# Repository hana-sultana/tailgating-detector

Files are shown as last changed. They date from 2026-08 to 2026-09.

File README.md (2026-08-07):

# AI-Powered Tailgating Detection and Driver Alert System

A low-cost, fully offline ADAS prototype. A rear-facing Raspberry Pi Camera
Module 3 feeds a Raspberry Pi 5 running YOLO26n + ByteTrack; when a vehicle
stays below a distance threshold in the ego lane for a sustained period, the
Pi pushes a Bluetooth Low Energy notification to the driver's phone.

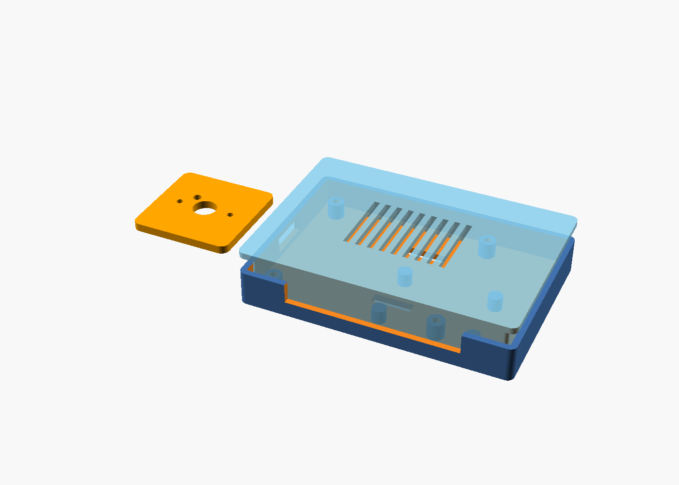
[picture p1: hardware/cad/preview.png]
Enclosure preview


## Architecture

```
Camera Module 3 ─CSI─> Raspberry Pi 5
                          │  Picamera2 capture (1280x720@30)
                          │  YOLO26n detection (imgsz=320, NMS-free)
                          │  ByteTrack persistent track IDs
                          │  Monocular distance (pinhole model + EMA smoothing)
                          │  Sliding-window decision (distance x time x lane)
                          └─BLE GATT notify──> Smartphone (nRF Connect / Flutter)
```

Everything runs on-device. No internet required or used.

## Repository layout

```
src/                   Python source (one module per pipeline stage)
  config.py            Every tunable, grouped by subsystem
  camera.py            Picamera2 backend + OpenCV fallback (video files!)
  detector.py          YOLO26n + ByteTrack wrapper
  distance_estimator.py  Pinhole-model distance + per-track smoothing
  tailgating_detector.py Decision logic (window, ratio, lane, cooldown)
  bluetooth.py         BLE GATT peripheral (bluezero/BlueZ)
  logger.py            Rotating logs + annotated event snapshots
  main.py              Entry point
tests/                 pytest unit tests for decision logic
hardware/
  cad/                 OpenSCAD source + printable STLs + preview
  diagrams/            Wiring and pinout
docs/                  BOM, calibration, testing, timeline, report skeleton
mobile/                Companion app design notes
```

## Install (on the Pi)

```bash
sudo apt update && sudo apt install -y python3-picamera2 bluez
git clone <your-repo-url> && cd tailgating-detector
python3 -m venv --system-site-packages .venv && source .venv/bin/activate
pip install ultralytics opencv-python numpy bluezero pytest
```

`--system-site-packages` lets the venv see the apt-installed picamera2.

## Run

```bash
cd src
python main.py                    # live camera
python main.py --video drive.mp4  # develop against recorded footage
python main.py --show             # with preview window (needs a display)
pytest ../tests -v                # decision-logic unit tests
```

First run downloads `yolo26n.pt` automatically. To receive alerts, open
nRF Connect on your phone, connect to **TailgateAlert**, and enable
notifications on the Alert characteristic.

## Key parameters (src/config.py)

| Parameter | Default | Meaning |
|---|---|---|
| `distance_threshold_m` | 8.0 | Closer than this = "too close" |
| `time_threshold_s` | 3.0 | Must persist this long |
| `violation_ratio` | 0.8 | Fraction of window frames below threshold |
| `lane_center_band` | 0.25 | Ego-lane filter (fraction of frame width) |
| `alert_cooldown_s` | 20.0 | Per-vehicle re-alert suppression |
| `imgsz` | 320 | Inference resolution (speed/accuracy trade) |

## Docs

- [Bill of Materials & cost](docs/BOM.md)
- [Wiring & assembly](hardware/diagrams/WIRING.md)
- [Camera calibration](docs/CALIBRATION.md)
- [Testing & validation plan](docs/TESTING.md)
- [Project timeline & risks](docs/TIMELINE.md)
- [Engineering report skeleton](docs/REPORT_OUTLINE.md)
- [Mobile app design](mobile/APP_DESIGN.md)

## Safety & legal notes

This is a driver-awareness prototype, not a certified safety device. It
must not be relied on for collision avoidance. Check local law before
mounting anything on a windshield/rear window, and mount the phone so
alerts don't create their own distraction (audio-only while driving).

## License

MIT (code). Note that Ultralytics YOLO weights are AGPL-3.0 — fine for a
personal/portfolio project; review licensing before any commercial use.

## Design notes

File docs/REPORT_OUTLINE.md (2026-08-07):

# Engineering Report — Outline & Research Direction

Skeleton for the final report (target 12–20 pages). Poster and slides
derive from the same structure.

1. **Abstract** — problem, approach, headline results (precision/recall,
   FPS, latency).
2. **Introduction & motivation** — rear-end collisions and tailgating as
   a factor; gap: production rear collision warning exists in new cars,
   not affordable retrofits.
3. **Related work** — see below.
4. **System design** — architecture diagram; hardware selection
   rationale (why Pi 5 / Camera Module 3 / BLE); enclosure design.
5. **Methodology** — YOLO26n choice & benchmarks; ByteTrack; pinhole
   distance model + calibration procedure; decision algorithm with the
   violation-ratio justification.
6. **Implementation** — module structure, offline-first constraints, BLE
   GATT design.
7. **Evaluation** — full metrics table from docs/TESTING.md; edge-case
   findings; thermal/power results.
8. **Limitations** — monocular depth assumptions, night performance,
   class-height bias, not a certified safety system.
9. **Future work** — ToF/radar fusion, Hailo acceleration, per-class
   heights, lane detection for curved-road filtering.
10. **Conclusion**, references, appendices (BOM, wiring, code listing).

## Research to cite (search terms → what it supports)

Find these on Google Scholar / arXiv and pick recent, well-cited
representatives — verify details before citing:

| Topic / search terms | Supports which section |
|---|---|
| "monocular distance estimation vehicle detection" | Methodology: pinhole model precedent & known error sources |
| "vision-based forward collision warning system" | Related work: the front-facing mirror of this project |
| "rear-end collision warning system" + NHTSA rear-end crash statistics | Motivation: problem scale |
| "ByteTrack multi-object tracking" (Zhang et al.) | Methodology: tracker choice |
| Ultralytics YOLO26 paper (arXiv 2606.03748) + "YOLO evolution overview" (arXiv 2510.09653) | Methodology: detector choice, NMS-free edge inference |
| "embedded deep learning inference Raspberry Pi benchmark" | Implementation: edge-AI feasibility |
| "time headway tailgating definition traffic safety" | Decision algorithm: the 2-second rule / headway literature justifies distance-x-time thresholds |
| "ADAS SAE J3016 levels" | Intro: where this sits (Level 0 warning system) |

Tip: the *time-headway* literature is the strongest academic anchor for
your decision rule — traffic engineering defines tailgating in seconds
of headway, not meters, which motivates a future version that scales
distance_threshold with ego speed (needs GPS/OBD speed input — good
future-work paragraph).

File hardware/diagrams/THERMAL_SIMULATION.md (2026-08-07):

# Thermal Simulation

## Why simulate thermal performance?

The Raspberry Pi 5's SoC dissipates around 6 W under sustained YOLO
inference. Enclosed in a plastic case inside a parked car that can hit
60 °C in Texas summer, the Pi is working against a bad starting
temperature with limited paths for heat to escape. If the SoC crosses
85 °C it throttles itself, which means detection slows down or stops
right when it matters. A thermal simulation lets us catch this problem
in software before printing plastic and mounting hardware in a car.

## Environmental context

The system is designed for use in Houston, Texas. Local summer highs
routinely reach 105 °F (40.5 °C), and a parked car's interior can
exceed 60 °C in direct sun. The 25 °C ambient value used in the
simulation below therefore represents a mild baseline, not a
worst-case operating condition. A follow-up run should sweep ambient
from 25 °C to 60 °C to characterize warm-weather performance.

## Approach

Ran a **steady-state heat transfer (solid conduction) analysis** in
SimScale using the sealed enclosure geometry
(`hardware/cad/case_combined.stl`).

The physics is deliberately simplified compared to a full conjugate
heat transfer simulation, which would also model the internal air
flow. STL files export a single triangle mesh, so SimScale sees the
enclosure as one solid body without a separate fluid region. Proper
conjugate heat transfer would need the case rebuilt as a multi-body
STEP model in Fusion 360. Solid-only conduction is a reasonable
first-order approach for looking at how heat spreads through the
plastic, but as documented in the results section below, it is not
sufficient by itself to answer the practical question of whether the
case works.

## Setup

| Parameter | Value | Notes |
|---|---|---|
| Physics | Heat Transfer (solid conduction) | Steady-state, linear |
| Geometry | `case_combined.stl` | Sealed base + lid, scaled to mm |
| Material | PET (thermal conductivity 0.2 W/m·K) | PETG proxy; within ~5% of PETG values |
| Heat source | 26,667 W/m² on interior floor face | 6 W spread over the case floor area |
| Heat sink | Fixed 25 °C on outer walls | First-order convection substitute |
| Mesh | ~450k cells, coarse (fineness = 1) | Sufficient for first-order thermal |

## Results

Case floor temperature distribution

The temperature field on the case floor shows the expected conduction
pattern: heat concentrates in the center (red) and spreads outward
through the plastic to the cooler outer walls (blue) where the
ambient boundary pulls heat away. The gradient is smooth and
physically consistent with 2D conduction from a distributed source.

## Important finding: results are unphysical

The color scale on the result shows a peak temperature of about
**1881 K (1608 °C)** at the center. PET plastic melts at around
260 °C, so this result cannot represent a real operating condition.
The simulation is telling us something real, but it is not "the case
gets to 1600 °C."

What actually happened: the model has a fixed 6 W of heat entering
through the floor and only conductive paths through the plastic walls
to a 25 °C boundary. The plastic is a poor conductor
(0.2 W/m·K). With no convection, no radiation, and no airflow through
the vents, the only way for the math to balance 6 W in against 6 W
out is for the temperature gradient to become extreme. The solver
kept climbing until it hit whatever temperature was needed to push
the heat through, ignoring that the material would have melted long
before that.

The takeaway is that solid-only conduction on its own is not a
sufficient model for this enclosure. The vents and the active cooler
are not incidental features that could be simplified away — they are
doing most of the cooling work. Any thermal result that ignores them
will over-predict internal temperature to the point of being
non-physical.

## Limitations

- **No airflow modeled.** This is the dominant limitation and the
  reason the result above is not physically meaningful. Real
  ventilation through the top vent slots plus the Pi 5 Active Cooler
  fan will significantly improve cooling.
- **No radiation modeled.** At the extreme temperatures the solver
  reached, radiative heat loss would be a major term in reality.
- **Uniform floor heat flux.** The real SoC is a 15 mm × 15 mm hot
  spot, not a distributed source. In a properly cooled model, the
  actual chip location would be hotter than what the simulation shows
  at that location.
- **Ambient boundary is idealized.** A parked car interior doesn't
  behave like a magic 25 °C wall; a full model would apply a
  convective boundary tied to expected in-cabin air temperature, and
  in Houston that boundary temperature is closer to 40–60 °C than
  25 °C.
- **Not validated against measurement.** No physical prototype was
  available to compare against.

## Future work

- Rebuild the enclosure in Fusion 360 as a proper solid + fluid
  assembly, exported as STEP, and re-run as conjugate heat transfer
  with the internal air region and vent openings modeled explicitly.
- Add the active cooler fan as a defined flow boundary once the fluid
  region exists.
- Sweep ambient temperature from 25 °C to 60 °C to bracket
  summer-parking behavior in Houston.
- Instrument the printed prototype with `vcgencmd measure_temp` and
  run a 30-minute sustained YOLO load. Compare the measured SoC
  temperature against the (updated) simulation. This is the real
  validation step.

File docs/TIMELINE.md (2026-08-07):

# Project Timeline & Risk Assessment

Assumes ~8–10 hrs/week alongside classes. 8 weeks to a demo-ready system.

| Week | Milestone | Deliverable |
|---|---|---|
| 1 | Hardware bring-up | Pi boots, camera verified (`rpicam-hello`), repo pushed |
| 2 | Detection running | YOLO26n on live camera, FPS benchmarked at 320/640 |
| 3 | Tracking + distance | Stable track IDs; calibrated distance within ±20% static |
| 4 | Decision logic | Unit tests pass; tuned on first recorded footage |
| 5 | BLE pipeline | Alert lands in nRF Connect end-to-end; latency measured |
| 6 | Enclosure + install | Case printed, mounted in vehicle, thermal/power validated |
| 7 | Validation | Tier 2–4 testing, metrics table filled in |
| 8 | Documentation | Report, README polish, demo video, poster/slides |

Stretch (weeks 9+): Flutter app, ToF sensor fusion, dashcam recording.

## Risk assessment

| Risk | Likelihood | Impact | Mitigation |
|---|---|---|---|
| FPS too low on Pi CPU | Medium | High | imgsz=320, yolo26n; escalate to Hailo AI Kit ($70) |
| Distance too inaccurate | Medium | Medium | Calibration; threshold-based design tolerates bias; ToF upgrade path |
| BLE drops in-vehicle | Low | Medium | Peripheral keeps advertising; phone auto-resubscribes; test Tier 3 |
| Thermal throttling in car | Medium | Medium | Active cooler, vented PETG case, thermal soak test |
| Undervoltage from car adapter | Medium | High | Spec'd 5V/5A PD adapter; `get_throttled` check in Tier 3 |
| SD corruption from power cuts | Medium | Low | Overlay filesystem (read-only root) |
| False positives annoy driver | Medium | Medium | violation_ratio + cooldown; tune on labeled footage first |
| Scope creep (app, extra features) | High | Medium | nRF Connect is the v1 phone client; Flutter is stretch only |

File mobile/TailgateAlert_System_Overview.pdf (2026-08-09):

# TailgateAlert System Overview

A simple overview of how TailgateAlert detects, sends, warns, and saves alerts.

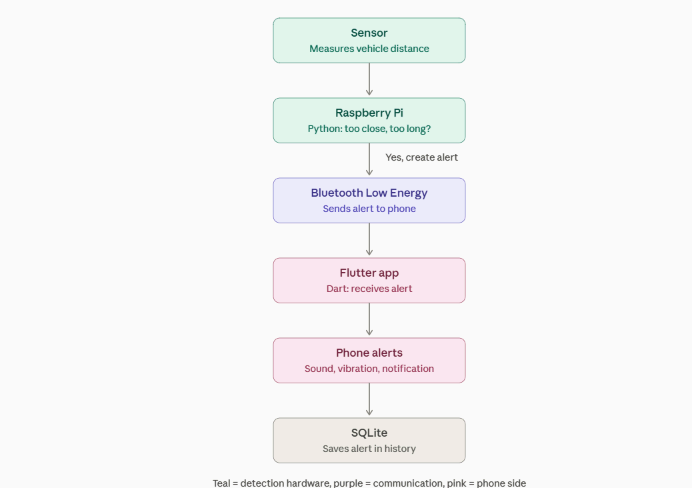
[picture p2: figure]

Figure 1. TailgateAlert system flow

## How It Works

1. Sensor: Measures how far away the vehicle behind you is.
1. The sensor repeatedly measures the distance to the vehicle behind us.
2. The Raspberry Pi compares that measurement with a configurable distance threshold.
3. If the vehicle stays inside that threshold, the Pi starts measuring how long it remains there.
4. The duration is calculated as the current time minus the time the close-following condition started.
5. If both the distance and duration conditions are met, the system creates an alert and sends it to the phone.
2. Raspberry Pi: Runs Python code that checks if the vehicle is too close for too long. If yes, it creates an alert.
3. Bluetooth Low Energy (BLE): Sends the alert from the Raspberry Pi to the phone.
4. Flutter App: Built with Flutter and Dart. It receives the Bluetooth alert.
5. Phone Alert: Plays a sound, vibrates, and shows a notification.
6. SQLite: Saves the alert on the phone so it can be viewed later in History.

## Code Idea

Raspberry Pi (Python)

distance = 6.4
time_close = 3.2 if distance < 8 and time_close >= 3:
print("Send tailgating alert")
Meaning: If the car is closer than 8 meters for at least 3 seconds, the Pi sends an alert.

Phone App (Flutter/Dart)

void receiveAlert() {
playSound();
vibrate();
showNotification();
saveToHistory();
}
Meaning: When an alert arrives, the phone warns the driver and saves the event.

## How to Run It

Raspberry Pi: python3 tailgate_alert.py

Flutter development: flutter run

After installation: Open the TailgateAlert app. It scans for the Pi, connects through BLE, and listens for alerts.

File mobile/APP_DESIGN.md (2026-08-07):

# Companion Mobile App Design

## Phase 1: nRF Connect (zero code, week 5)

Scan → connect to **TailgateAlert** → expand the custom service → enable
notifications on the Alert characteristic (8e7c1a41-...). Each event
arrives as compact JSON. Good enough to demo the full pipeline.

## Phase 2: Custom app — Flutter (recommended over React Native)

Why Flutter: `flutter_blue_plus` is the most mature cross-platform BLE
library, background BLE behaves better than in the React Native BLE
ecosystem, and a single Dart codebase covers Android + iOS. React Native
is the better pick only if you already know React deeply — you don't
lose much either way, but BLE is the make-or-break dependency and
Flutter's story is stronger.

## Screens

```
┌──────────────────────┐  ┌──────────────────────┐  ┌──────────────────────┐
│ HOME                 │  │ HISTORY              │  │ SETTINGS             │
│                      │  │                      │  │                      │
│   ● Connected        │  │ Today                │  │ Distance threshold   │
│   TailgateAlert      │  │ ├ 4:12p  6.4m  3.2s  │  │ [====|----] 8 m      │
│                      │  │ ├ 3:48p  7.1m  4.0s  │  │ Time threshold       │
│   Last alert:        │  │ Yesterday            │  │ [==|------] 3 s      │
│   6.4 m for 3.2 s    │  │ ├ 5:02p  5.9m  6.1s  │  │ Alert sound  [on]    │
│   2 min ago          │  │                      │  │ Vibrate      [on]    │
│                      │  │ (tap → event detail) │  │ Auto-reconnect [on]  │
│ [ Reconnect ]        │  │                      │  │                      │
└──────────────────────┘  └──────────────────────┘  └──────────────────────┘
```

- **Home**: connection state (scanning / connected / lost), last alert
  card, big reconnect button.
- **History**: local list of received events (JSON payloads persisted to
  SQLite), grouped by day.
- **Settings**: thresholds shown for reference (v1: read-only mirror of
  Pi config; v2: writable via a config BLE characteristic), sound/vibe
  toggles, auto-reconnect.

## Notification behavior

- Foreground: in-app banner + sound.
- Background: local push notification ("Vehicle following closely —
  6.4 m for 3.2 s") triggered from the BLE characteristic callback.
- Driving safety: default to sound/vibration; the driver should never
  need to look at the phone.

## Connection logic

```
start → scan(name=TailgateAlert, 10 s) → connect → discover service
      → subscribe(alert char) → listening
on disconnect → backoff scan loop (1 s, 2 s, 5 s, … cap 30 s) → reconnect
```

The Pi side needs no reconnection logic — as a peripheral it just keeps
advertising.

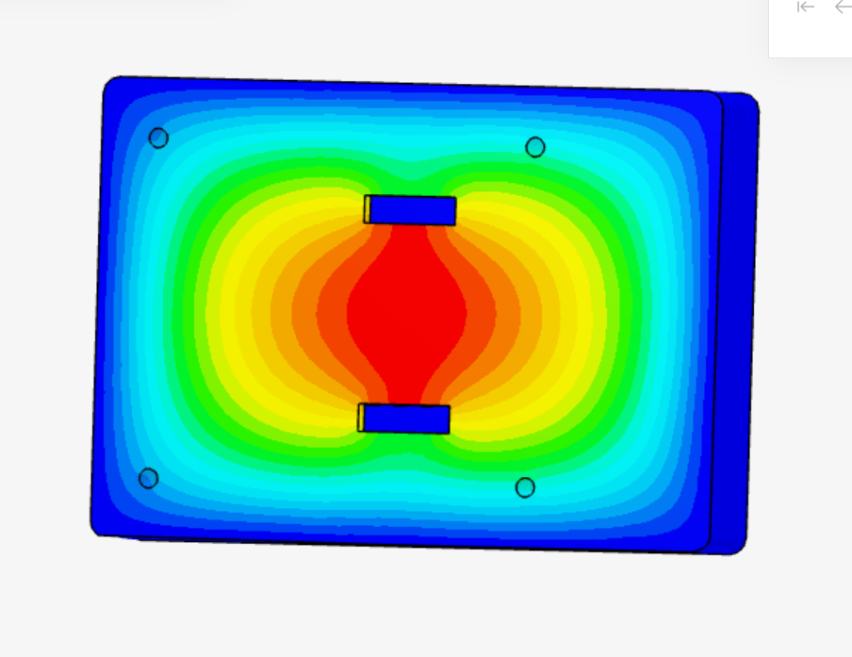
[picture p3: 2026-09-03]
hardware/thermalsim.png

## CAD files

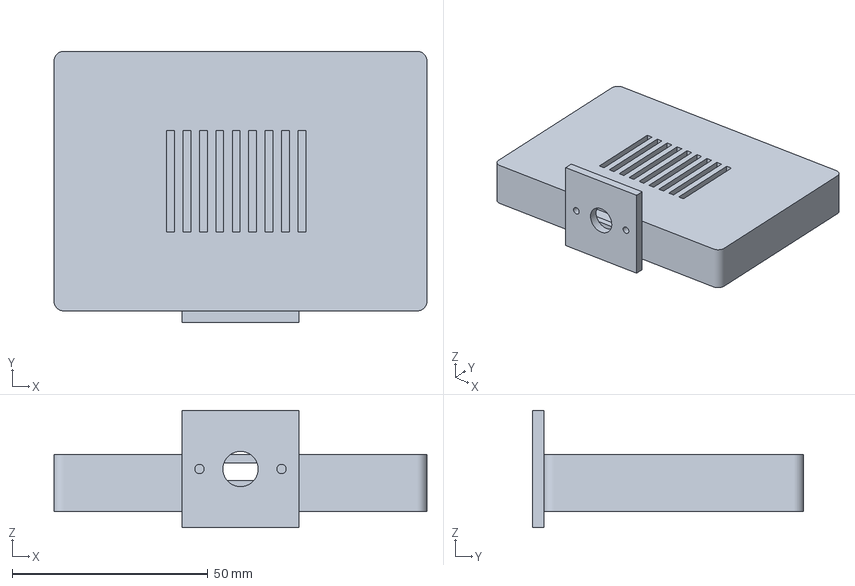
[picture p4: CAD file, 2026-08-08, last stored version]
hardware/cad/case_integrated (1).3mf
95.4 x 69.4 x 30.0 mm

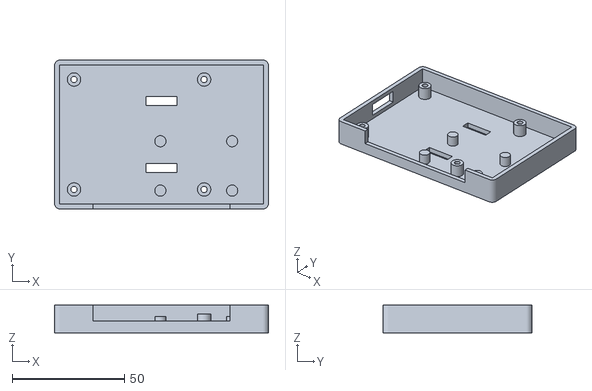
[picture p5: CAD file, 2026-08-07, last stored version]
hardware/cad/base.stl
95.4 x 66.4 x 12.4

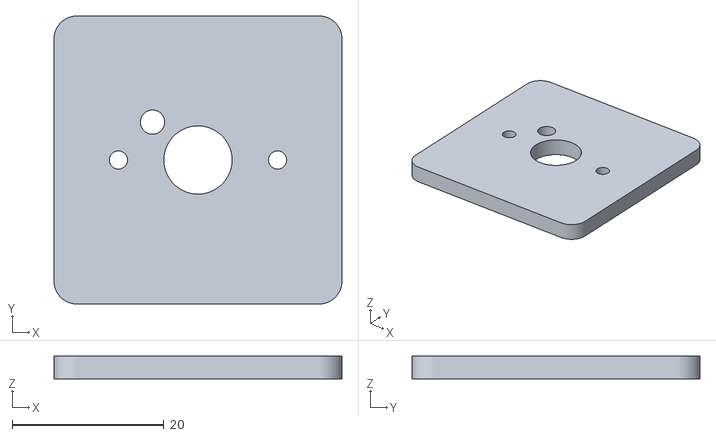
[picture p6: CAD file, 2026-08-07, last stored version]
hardware/cad/camera.stl
38.0 x 38.0 x 3.00

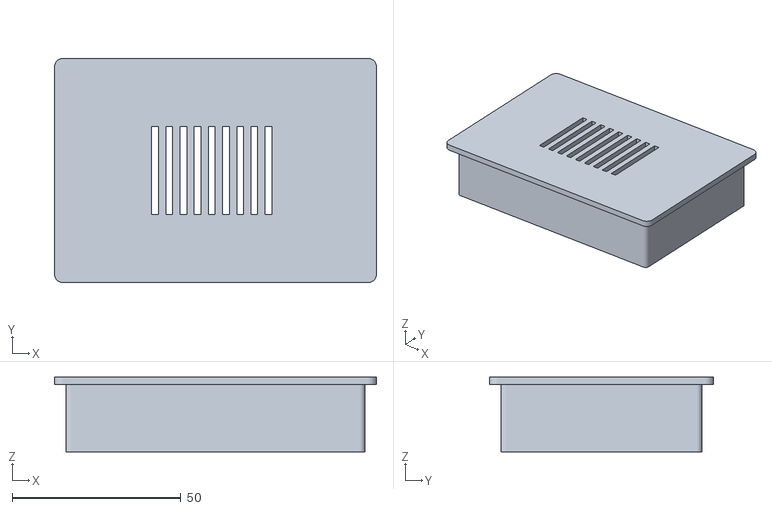
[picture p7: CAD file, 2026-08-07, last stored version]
hardware/cad/lid.stl
95.4 x 66.4 x 22.2

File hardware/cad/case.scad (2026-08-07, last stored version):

// ============================================================
//  Rear-Tracker Case v1 — Raspberry Pi 5 + alert board + camera mount
// ============================================================
//  PART = "base"      -> main enclosure tray (Pi + alert-board standoffs)
//  PART = "lid"        -> vented lid w/ IO + CSI ribbon cutouts
//  PART = "camera"     -> small rear camera bracket (Camera Module 3)
//  PART = "assembly"   -> all three shown together, for a quick look
//
//  Render one part at a time for printing, e.g.:
//     openscad -D 'PART="base"'   -o base.stl   case.scad
//     openscad -D 'PART="lid"'    -o lid.stl    case.scad
//     openscad -D 'PART="camera"' -o camera.stl case.scad
//
//  Notes:
//  - Pi board footprint (85x56mm) and mounting-hole pattern (58x49mm,
//    3.5mm inset) are the standard Pi spec, unchanged since Model B+,
//    so these should be accurate.
//  - Port cutouts are modeled as one generous slot per edge rather
//    than tight per-connector holes, on purpose — verify against the
//    official Pi 5 mechanical drawing (raspberrypi.com) before printing
//    if you want a tighter-fitting result.
//  - Lid is a friction-fit skirt. Fine for a bench test; for something
//    that lives in a car, add a dab of hot glue or two M2 screws once
//    you're happy with the fit — vibration will work a pure friction
//    fit loose over time.
// ============================================================

PART = "assembly";   // "base" | "lid" | "camera" | "assembly"

// ---- Pi 5 board ----
pi_len = 85; pi_wid = 56;
hole_inset = 3.5; hole_span_x = 58; hole_span_y = 49; hole_d = 2.8;
component_h = 17;                 // top-side keepout: HDMI/USB stack + margin

// ---- shell ----
wall = 2.2; floor_h = 2.4; standoff_h = 6;
lid_wall_h = component_h + 3;     // lid skirt depth
fillet_r = 2.5;

// ---- alert board (buzzer / LED / arm-button perfboard) ----
alert_w = 40; alert_d = 30; alert_standoff_h = 5;

// ---- cutouts ----
port_slot_w = pi_len - 24; port_slot_h = 14;
csi_slot_w = 16; csi_slot_h = 6;
vent_n = 9; vent_w = 2; vent_gap = 4.2; vent_len = 26;

// ---- zip-tie mount channels (through the base floor) ----
tie_slot_w = 4; tie_slot_len = 14; tie_spacing = 30;

$fn = 48;

module rounded_box(x, y, z, r) {
    hull()
        for (dx = [r, x - r])
            for (dy = [r, y - r])
                translate([dx, dy, 0]) cylinder(h = z, r = r);
}

outer_x = pi_len + 2*wall + 6;
outer_y = pi_wid + 2*wall + 6;
outer_z = floor_h + standoff_h + 4;

module base() {
    difference() {
        union() {
            difference() {
                rounded_box(outer_x, outer_y, outer_z, fillet_r);
                // hollow interior, open top
                translate([wall, wall, floor_h])
                    cube([outer_x - 2*wall, outer_y - 2*wall, outer_z]);
                // IO port slot (long edge)
                translate([(outer_x - port_slot_w)/2, -1, floor_h + 3])
                    cube([port_slot_w, wall + 2, port_slot_h]);
                // CSI ribbon slot (short edge, toward the camera side)
                translate([-1, outer_y/2 - csi_slot_w/2, floor_h + 2])
                    cube([wall + 2, csi_slot_w, csi_slot_h]);
                // zip-tie channels through the floor
                for (yoff = [-tie_spacing/2, tie_spacing/2])
                    translate([outer_x/2 - tie_slot_len/2, outer_y/2 + yoff - tie_slot_w/2, -1])
                        cube([tie_slot_len, tie_slot_w, floor_h + 2]);
            }
            // Pi mounting standoffs (added back in solid, after hollowing)
            for (dx = [hole_inset, hole_inset + hole_span_x])
                for (dy = [hole_inset, hole_inset + hole_span_y])
                    translate([dx + 3 + wall, dy + 3 + wall, floor_h])
                        cylinder(h = standoff_h, d = 6);
            // alert-board standoffs, tucked in the corner beside the Pi
            for (dx = [0, alert_w - 8])
                for (dy = [0, alert_d - 8])
                    translate([outer_x - alert_w - wall - 6 + dx, wall + 6 + dy, floor_h])
                        cylinder(h = alert_standoff_h, d = 5);
        }
        // Pi screw holes, punched through the standoffs last
        for (dx = [hole_inset, hole_inset + hole_span_x])
            for (dy = [hole_inset, hole_inset + hole_span_y])
                translate([dx + 3 + wall, dy + 3 + wall, -1])
                    cylinder(h = standoff_h + 6, d = hole_d);
    }
}

module lid() {
    difference() {
        rounded_box(outer_x, outer_y, wall, fillet_r);
        // vent slots, roughly above the SoC
        for (i = [0 : vent_n - 1])
            translate([outer_x/2 - (vent_n*vent_gap)/2 + i*vent_gap, outer_y/2 - vent_len/2, -1])
                cube([vent_w, vent_len, wall + 2]);
    }
    // skirt that presses down inside the base tray
    translate([wall + 1.2, wall + 1.2, -lid_wall_h])
        difference() {
            rounded_box(outer_x - 2*wall - 2.4, outer_y - 2*wall - 2.4, lid_wall_h, fillet_r - 1);
            translate([1.4, 1.4, -1])
                rounded_box(outer_x - 2*wall - 5.2, outer_y - 2*wall - 5.2, lid_wall_h + 2, max(fillet_r - 1.5, 0.5));
        }
}

module camera_mount() {
    // Camera Module 3 board is roughly 25x24mm w/ two mounting holes —
    // double check against your specific camera board before drilling tight.
    cam_hole_span = 21; lens_d = 9; plate_t = 3;
    pw = 26 + 12; ph = 26 + 12;
    difference() {
        rounded_box(pw, ph, plate_t, 3);
        translate([pw/2, ph/2, -1]) cylinder(h = plate_t + 2, d = lens_d);
        for (dx = [-cam_hole_span/2, cam_hole_span/2])
            translate([pw/2 + dx, ph/2, -1]) cylinder(h = plate_t + 2, d = 2.4);
        // strap/zip-tie holes for mounting to a window bracket
        for (yoff = [-8, 8])
            translate([pw/2 - 6, ph - 6 + yoff, -1])
                cylinder(h = plate_t + 2, d = 3.2);
    }
}

module assembly_preview() {
    base();
    translate([0, 0, outer_z + 6]) color("SkyBlue", 0.85) lid();
    translate([-(outer_x*0.55), outer_y*0.25, 4]) color("Orange") camera_mount();
}

if (PART == "base") base();
else if (PART == "lid") lid();
else if (PART == "camera") camera_mount();
else assembly_preview();

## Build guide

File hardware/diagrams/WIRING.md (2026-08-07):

# Wiring, Pinout, and Assembly

This build is deliberately low-wiring: two cables total in the base
configuration (camera ribbon + USB-C power). BLE replaces all signal
wiring to the driver.

## Connection map

```
[12V socket] --> [USB-C PD car adapter, 5V/5A] --USB-C--> [Pi 5 power in]

[Camera Module 3] ==22-pin ribbon (CAM/DISP 0)==> [Pi 5]

[Pi 5 BLE radio] ~~~~2.4 GHz~~~~> [Smartphone]
```

## Camera ribbon (the one fiddly step)

1. Pi 5 has two mini (22-pin) CSI ports labeled CAM/DISP 0 and 1 — use
   **CAM/DISP 0** (matches config default).
2. Ribbon contacts face **inward toward the USB ports** on the Pi side;
   on the camera side, contacts face the camera PCB. Blue stiffener
   faces away from contacts on both ends.
3. Lift the black latch, seat the ribbon fully and squarely, press the
   latch closed. A half-seated ribbon = "no camera found".
4. Verify: `rpicam-hello --list-cameras`

## Optional ToF sensor (VL53L1X, sensor-fusion upgrade)

| VL53L1X pin | Pi 5 pin (physical) | Function |
|---|---|---|
| VIN | 1 (3V3) | Power |
| GND | 6 (GND) | Ground |
| SDA | 3 (GPIO2/SDA1) | I2C data |
| SCL | 5 (GPIO3/SCL1) | I2C clock |

Enable I2C via `sudo raspi-config` → Interface Options. Verify with
`i2cdetect -y 1` (device at 0x29).

## Assembly order

1. Fit the active cooler to the Pi (before anything else — it needs
   clear board access).
2. Screw the Pi onto the base-tray standoffs (4× M2.5).
3. Route the camera ribbon out the side CSI slot in the base.
4. Connect USB-C through the IO slot.
5. Press the lid on; verify vents sit over the cooler.
6. Mount base to parcel shelf with zip ties through the floor channels
   (or VHB tape). Camera bracket mounts to the rear glass area, lens
   facing traffic, roughly level; zip-tie holes provided.

## In-vehicle placement notes

- Rear parcel shelf (sedan) or trunk-lid interior trim (hatch) both work;
  keep the lens unobstructed by the wiper/defroster lines where possible.
- Power from the 12 V socket means the system powers on with the
  ignition — no battery drain, and clean shutdown matters less because
  the filesystem sees mostly-read workloads once running (still: enable
  overlay filesystem in raspi-config for robustness against hard cuts).

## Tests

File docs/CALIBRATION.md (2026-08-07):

# Camera Calibration for Distance Estimation

The estimator uses the pinhole model: `D = f · H / h`, with focal length
`f` (pixels) derived from the FoV spec by default. A 10-minute one-point
calibration replaces the spec value with a measured one and removes most
systematic bias.

## One-point calibration (do this)

1. Park. Place a second car (or have a helper park) directly behind at a
   **measured** distance — tape-measure 10.0 m from lens to car front.
2. Run `python main.py --show` and read the bbox height `h_px` of that
   car from a saved event frame or by adding a debug print.
3. Compute: `f = D · h / H = 10.0 · h_px / 1.5`
4. Put the result in `config.py`:
   `calibrated_focal_length_px = <your f>`
5. Re-verify at 5 m and 15 m; error should be within ±15%.

## Expected accuracy

| Source of error | Magnitude | Mitigation |
|---|---|---|
| Vehicle height assumption (1.5 m) | ±20% car vs SUV | Per-class heights (future) |
| Bbox jitter | ±5–10% frame-to-frame | EMA smoothing (built in) |
| Lens distortion at frame edges | grows off-center | Lane filter keeps targets central |
| Pitch changes (braking/bumps) | transient | Time window absorbs transients |

For a *threshold-based* alert, consistency matters more than absolute
accuracy — calibrate once, then tune `distance_threshold_m` empirically
on real footage until alerts match your judgment of "too close".

## Full checkerboard calibration (optional, for the report)

OpenCV's `calibrateCamera` with a printed 9×6 checkerboard yields the
full intrinsic matrix + distortion coefficients — great material for the
engineering report's methodology section, and enables undistortion if
you switch to the Wide camera. See OpenCV's calibration tutorial;
~20 board poses is plenty.

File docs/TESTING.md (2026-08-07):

# Testing & Validation Plan

Four tiers, cheapest first. Never tune on public roads — tune on
recorded footage, then validate.

## Tier 1 — Unit tests (done, automated)

`pytest tests/ -v` covers the decision logic: sustained-close fires,
brief pass doesn't, far never, adjacent lane filtered, cooldown works,
jitter tolerated. Run on every commit (add GitHub Actions later).

## Tier 2 — Recorded-footage evaluation (main development loop)

1. Mount the camera, record 30–60 min of normal driving with
   `rpicam-vid` (varied: highway, city, night, rain if possible).
2. Hand-label tailgating segments (start/end timestamps) — your ground
   truth.
3. Run `python main.py --video clip.mp4`; compare fired events to labels.

**Metrics to report:**

| Metric | Definition | Target |
|---|---|---|
| Precision | true alerts / all alerts | ≥ 0.8 |
| Recall | true alerts / labeled events | ≥ 0.8 |
| Alert latency | time from threshold crossing to BLE notify | ≤ 1 s beyond time_threshold |
| Throughput | pipeline FPS on Pi 5 | ≥ 10 FPS at imgsz=320 |
| Distance error | vs tape measure at 5/10/15 m (static) | ≤ ±20% |

## Tier 3 — Static & parking-lot tests

- Distance accuracy: parked cars at measured distances (see CALIBRATION).
- BLE range/reliability: phone in cabin, Pi in trunk — alert delivery
  rate over 50 induced events; reconnection after walking out of range.
- Thermal soak: 30 min sustained inference; log
  `vcgencmd measure_temp` — must stay < 80 °C (throttle point 85 °C).
- Power: confirm no undervoltage flags (`vcgencmd get_throttled` → 0x0)
  on the car adapter.

## Tier 4 — On-road validation (passenger operates, driver drives)

Predefined, safe scenarios only — you never create tailgating yourself:
normal following traffic, stop-and-go, highway merge zones. Log
everything; review event snapshots afterward for false positives.

## Edge cases to test explicitly

- Motorcycles (smaller H → distance overestimated; note in report)
- Trucks/buses (larger H → underestimated; consider per-class heights)
- Night: headlight bloom; test detection confidence at night
- Rain on rear glass; defroster line occlusion
- Ego vehicle turning (lane filter behavior through curves)
- Vehicle approaching fast then backing off (should NOT alert)
- Two vehicles swapping (track ID switches — does cooldown map sensibly?)
- Tunnel/exposure swings; low sun directly into lens
- BLE: phone screen off, app backgrounded, phone rebooted mid-drive

## Stress tests

- 2-hour continuous run: memory RSS flat? (watch with `psutil`/`top`)
- Dense traffic clip (10+ vehicles/frame): FPS floor and latency
- SD card: overlay filesystem on, hard power-cut 10×, verify boot

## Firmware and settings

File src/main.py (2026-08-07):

"""Entry point: capture -> detect/track -> distance -> decide -> alert.

Usage
-----
  python main.py                 # live camera (Pi)
  python main.py --video x.mp4   # run against recorded footage (dev)
  python main.py --show          # display annotated preview window

Runs entirely offline; BLE is the only radio used.
"""

from __future__ import annotations

import argparse
import logging
import signal
import time

from bluetooth import BleAlertServer
from camera import create_camera
from config import CONFIG
from detector import VehicleDetector
from distance_estimator import DistanceEstimator
from logger import save_event_frame, setup_logging
from tailgating_detector import TailgatingDetector

log = logging.getLogger("main")

_running = True


def _stop(*_):
    global _running
    _running = False


def main() -> None:
    parser = argparse.ArgumentParser(description="Tailgating detection system")
    parser.add_argument("--video", help="video file instead of live camera")
    parser.add_argument("--show", action="store_true", help="preview window")
    args = parser.parse_args()

    setup_logging(CONFIG.logging)
    signal.signal(signal.SIGINT, _stop)
    signal.signal(signal.SIGTERM, _stop)

    camera = create_camera(CONFIG.camera, source=args.video)
    detector = VehicleDetector(CONFIG.detector)
    estimator = DistanceEstimator(CONFIG.distance, CONFIG.camera)
    decider = TailgatingDetector(CONFIG.tailgating, CONFIG.camera.width)
    ble = BleAlertServer(CONFIG.ble)
    ble.start()

    if args.show:
        import cv2

    frames, t0 = 0, time.monotonic()
    log.info("Pipeline running. Ctrl+C to stop.")
    try:
        while _running:
            frame = camera.read()
            if frame is None:
                log.info("End of stream.")
                break

            vehicles = detector.detect_and_track(frame)
            active = {v.track_id for v in vehicles}

            for v in vehicles:
                d = estimator.estimate(v)
                event = decider.update(v, d)
                if event:
                    log.warning(
                        "TAILGATING: id=%d dist=%.1fm dur=%.1fs",
                        event.track_id, event.distance_m, event.duration_s,
                    )
                    ble.send_alert(event)
                    save_event_frame(CONFIG.logging, frame, v, event)

            estimator.forget(active)
            decider.prune(active)

            frames += 1
            if frames % 100 == 0:
                fps = frames / (time.monotonic() - t0)
                log.info("throughput: %.1f FPS", fps)

            if args.show:
                for v in vehicles:
                    cv2.rectangle(
                        frame,
                        (int(v.x1), int(v.y1)),
                        (int(v.x2), int(v.y2)),
                        (0, 255, 0), 2,
                    )
                cv2.imshow("tailgate", frame)
                if cv2.waitKey(1) & 0xFF == ord("q"):
                    break
    finally:
        camera.release()
        log.info("Shut down cleanly.")


if __name__ == "__main__":
    main()

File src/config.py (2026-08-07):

"""Central configuration for the tailgating detection system.

Every tunable lives here so field calibration never requires touching
pipeline code. Values are grouped by subsystem.
"""

from dataclasses import dataclass, field


@dataclass(frozen=True)
class CameraConfig:
    width: int = 1280
    height: int = 720
    fps: int = 30
    # Camera Module 3 wide: 102 deg horizontal FoV. Standard: 66 deg.
    horizontal_fov_deg: float = 66.0
    device_index: int = 0  # used only by the OpenCV fallback backend


@dataclass(frozen=True)
class DetectorConfig:
    # yolo26n = latest nano model (Jan 2026), NMS-free, fastest on Pi CPU.
    # Fallback to "yolo11n.pt" if your ultralytics version predates it.
    model_path: str = "yolo26n.pt"
    confidence_threshold: float = 0.4
    # COCO class ids: 2=car, 3=motorcycle, 5=bus, 7=truck
    vehicle_class_ids: tuple = (2, 3, 5, 7)
    # Inference size. 320 nearly doubles FPS vs 640 at some accuracy cost;
    # rear-view targets are large, so 320 is usually fine.
    imgsz: int = 320
    # Ultralytics built-in tracker config ("bytetrack.yaml" or "botsort.yaml")
    tracker: str = "bytetrack.yaml"


@dataclass(frozen=True)
class DistanceConfig:
    """Monocular distance estimation via the pinhole-camera model.

    distance_m = (real_height_m * focal_length_px) / bbox_height_px

    focal_length_px is derived from FoV and image width at runtime;
    override with a calibrated value for better accuracy (see
    docs/CALIBRATION.md).
    """
    assumed_vehicle_height_m: float = 1.5   # avg passenger car
    calibrated_focal_length_px: float | None = None
    # Exponential smoothing on per-track distance to damp bbox jitter.
    smoothing_alpha: float = 0.35


@dataclass(frozen=True)
class TailgatingConfig:
    # Distance below which a follower is "too close".
    distance_threshold_m: float = 8.0
    # Continuous seconds below threshold before an alert fires.
    time_threshold_s: float = 3.0
    # A track must exceed this lateral-center band to count as "behind us"
    # (fraction of frame width from center). Filters adjacent-lane cars.
    lane_center_band: float = 0.25
    # Cooldown between alerts for the same track id.
    alert_cooldown_s: float = 20.0
    # Fraction of frames within the window that must violate the threshold
    # (tolerates missed detections without resetting the timer).
    violation_ratio: float = 0.8


@dataclass(frozen=True)
class BleConfig:
    device_name: str = "TailgateAlert"
    # Custom 128-bit UUIDs (randomly generated for this project)
    service_uuid: str = "8e7c1a40-52ce-4f4e-b1f5-2f3d6a9c0e11"
    alert_char_uuid: str = "8e7c1a41-52ce-4f4e-b1f5-2f3d6a9c0e11"
    status_char_uuid: str = "8e7c1a42-52ce-4f4e-b1f5-2f3d6a9c0e11"


@dataclass(frozen=True)
class LoggingConfig:
    log_dir: str = "logs"
    log_level: str = "INFO"
    # Save annotated frames of alert events for later review/debugging.
    save_event_frames: bool = True
    event_frame_dir: str = "logs/events"


@dataclass(frozen=True)
class AppConfig:
    camera: CameraConfig = field(default_factory=CameraConfig)
    detector: DetectorConfig = field(default_factory=DetectorConfig)
    distance: DistanceConfig = field(default_factory=DistanceConfig)
    tailgating: TailgatingConfig = field(default_factory=TailgatingConfig)
    ble: BleConfig = field(default_factory=BleConfig)
    logging: LoggingConfig = field(default_factory=LoggingConfig)


CONFIG = AppConfig()

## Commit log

2026-08-20 Rename hardware/cad/Screenshot 2026-08-04 011254.png to hardware/case_bottom
2026-09-03 how the heat will flow in the case
